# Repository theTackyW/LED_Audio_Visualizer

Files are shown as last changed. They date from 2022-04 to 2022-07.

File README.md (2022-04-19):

# LED_Audio_Visualizer
### Light DJ project

- This personal project utilizes MSGEQ7 to divide incoming audio signal into seven frequency bands and represents them as spectrum on 7 corresponding NeoPixel Sticks
Audio signal can be recieved by either a 3.5mm headphone jack or a microphone.

## Arduino Program and Functions
### LED_Audio_Visualizer.ino

> **void loop()**
> 
> - main function that read outputs of MSGEQ7, volume sensitivity nobe(volSen), and brightness nobe(brightControl); Update NeoPixel Sticks status.

> **void SingleLED(int v, int band)**
> 
> - Reads the output from MSGEQ7 for one specific band. Compare value with threadholds to determine how many LEDs need to be light up for each band

> **void setLEDnum(int n, int band, double bright)**
> 
> - function that uses .setPixelColor() function in the included <Adafruit_NeoPixel.h>. Considers brightness and color.
> calls the colorFade functions for color fade from [r1,g1,b1] to [r2,g2,b2] based on band level

> **void clearAll(int band)**
> 
> - set all LEDs on one band to OFF

> **double colorFadeR(int r1, int r2, int n)**

> **double colorFadeG(int g1, int g2, int n)**

> **double colorFadeB(int b1, int b2, int n)**

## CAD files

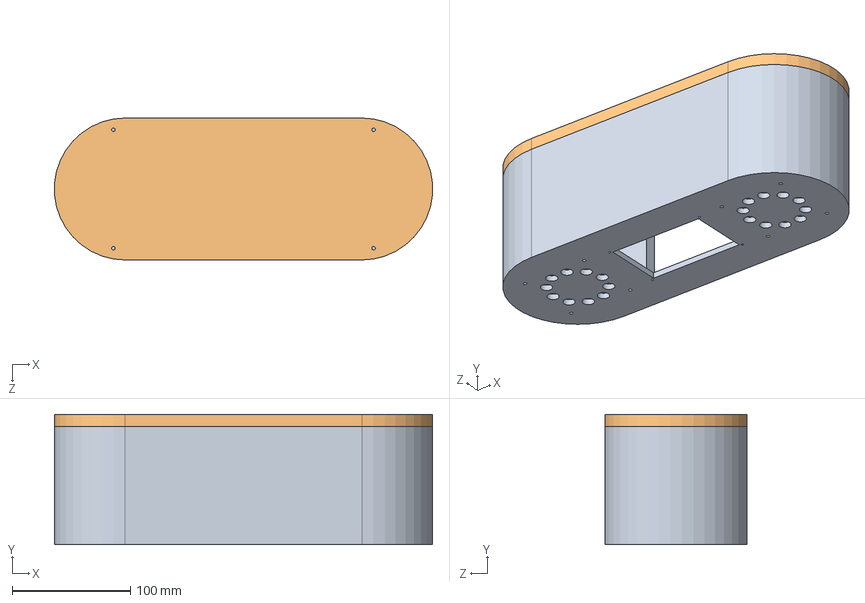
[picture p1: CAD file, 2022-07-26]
CAD/Speaker-case.SLDASM
319.6 x 110.0 x 120.0 mm
Front-case
back

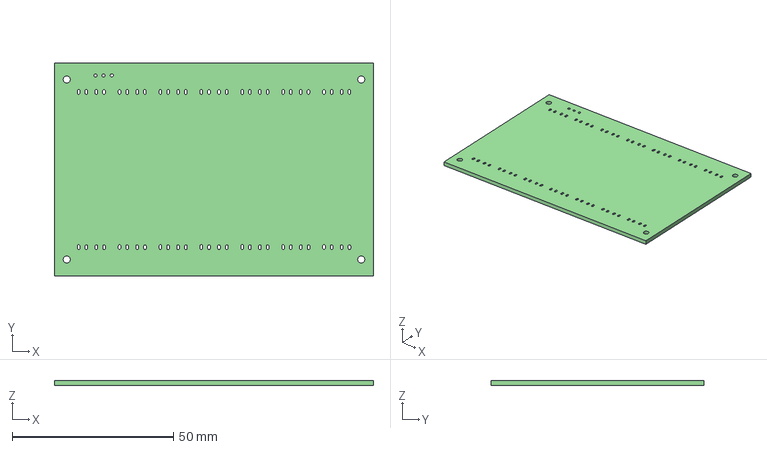
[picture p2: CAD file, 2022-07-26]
Adafruit_NeoPixel_bar/Adafruit_NeoPixel_bar.step
99.1 x 66.0 x 1.60 mm

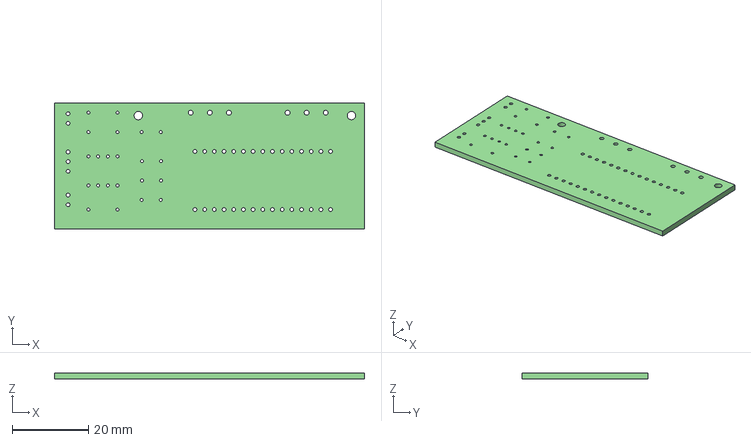
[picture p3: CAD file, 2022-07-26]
AV_Speaker/AV_Speaker.step
81.3 x 33.0 x 1.60 mm

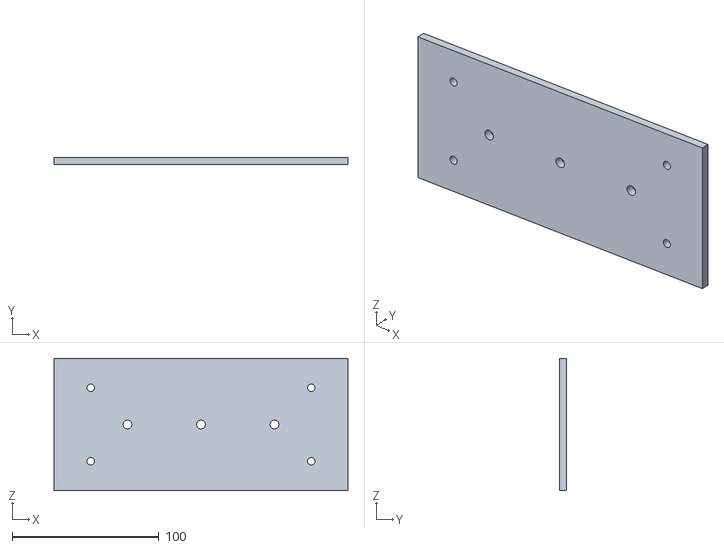
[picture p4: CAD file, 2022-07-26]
CAD/Top-cover.STL
200.0 x 5.00 x 90.0

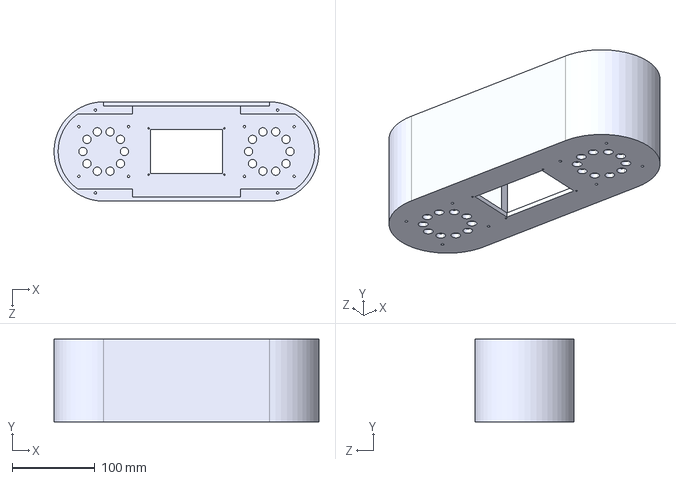
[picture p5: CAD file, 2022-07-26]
CAD/Front-case.STEP
320.0 x 100.0 x 120.0 mm

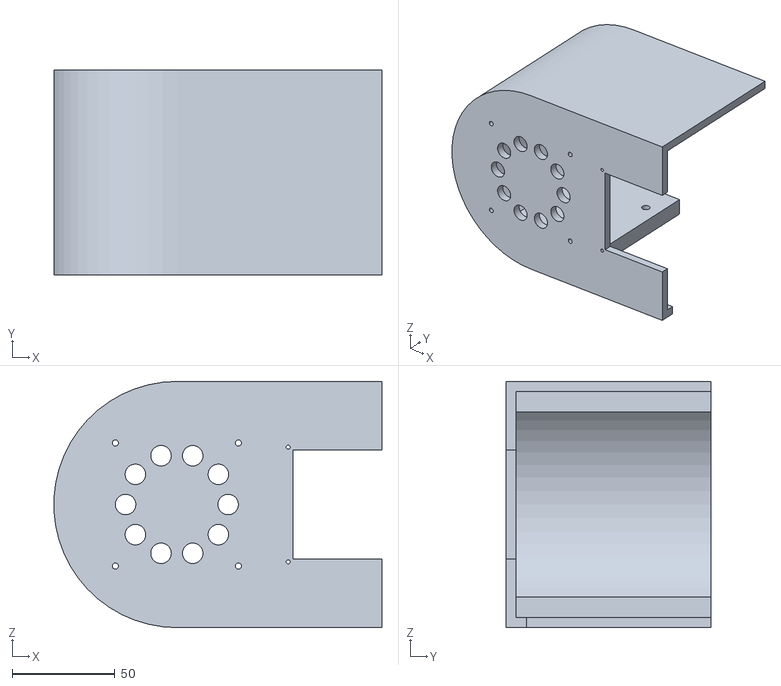
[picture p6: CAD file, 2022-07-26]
CAD/Front-case-right.STL
159.9 x 100.0 x 120.0

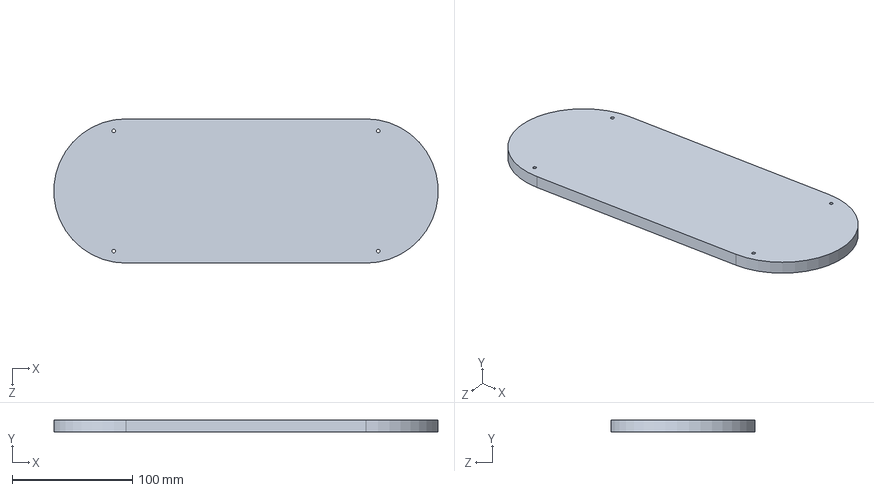
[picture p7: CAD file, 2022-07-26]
CAD/back.SLDPRT
319.6 x 10.0 x 120.0 mm

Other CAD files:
CAD/Front-case - left.STL
CAD/Front-case.SLDPRT
CAD/Front-case.STL

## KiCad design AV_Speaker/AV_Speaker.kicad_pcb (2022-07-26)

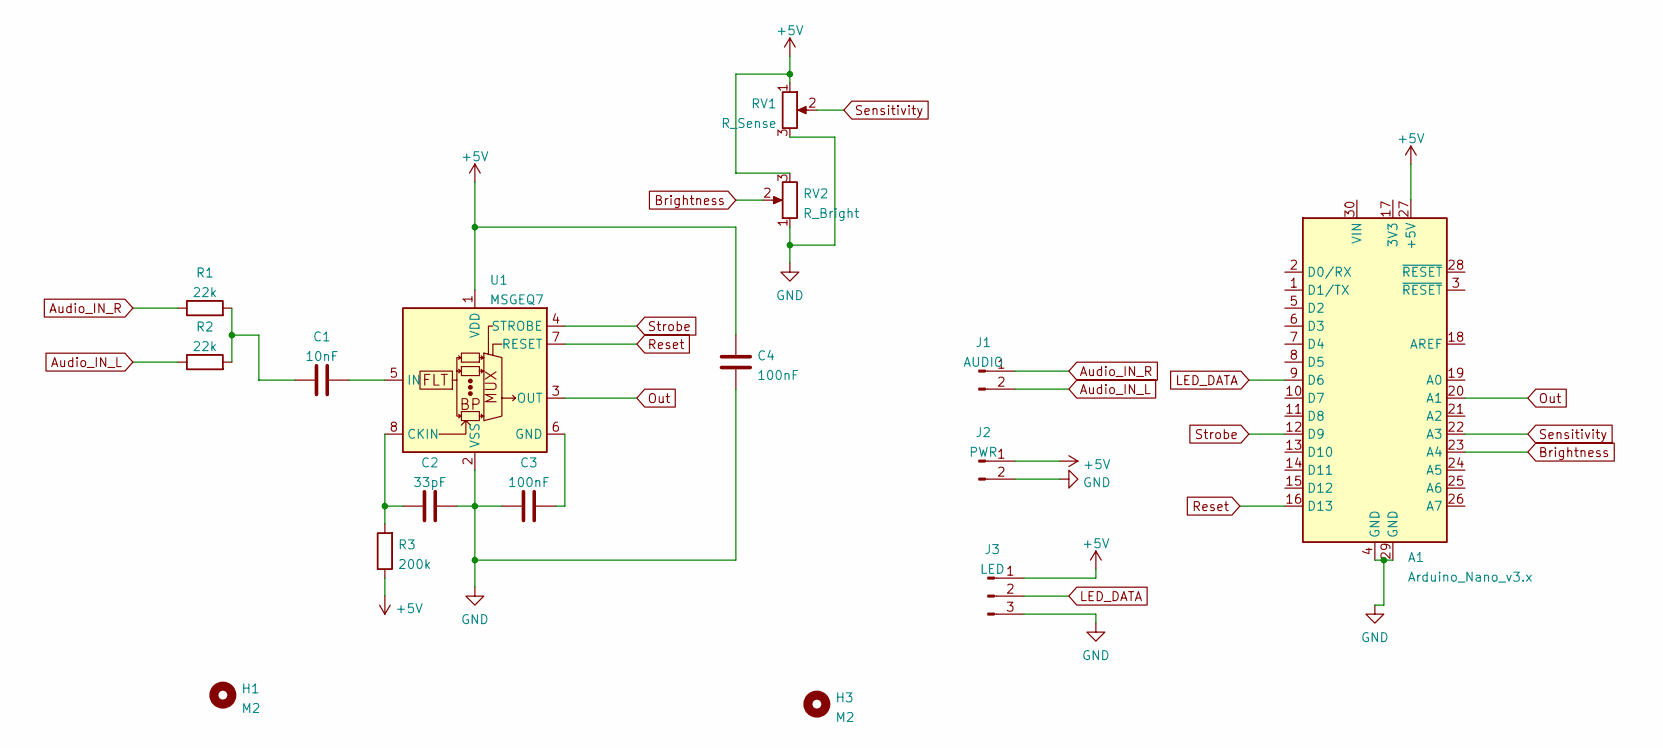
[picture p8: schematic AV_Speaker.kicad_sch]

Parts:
A1: Arduino_Nano_v3.x; Arduino_Nano
C1: 10nF; C_Disc_D4.3mm_W1.9mm_P5.00mm
C2: 33pF; C_Disc_D4.3mm_W1.9mm_P5.00mm
C3, C4: 100nF; C_Disc_D4.3mm_W1.9mm_P5.00mm
H1, H3: M2; MountingHole_2.2mm_M2
J1: AUDIO; PinHeader_1x02_P2.54mm_Vertical
J2: PWR; PinHeader_1x02_P2.54mm_Vertical
J3: LED; PinHeader_1x03_P2.54mm_Vertical
R1, R2: 22k; R_Axial_DIN0207_L6.3mm_D2.5mm_P7.62mm_Horizontal
R3: 200k; R_Axial_DIN0207_L6.3mm_D2.5mm_P7.62mm_Horizontal
RV1: R_Sense; Potentiometer_Piher_PC-16_Single_Horizontal
RV2: R_Bright; Potentiometer_Piher_PC-16_Single_Horizontal
U1: MSGEQ7; DIP-8_W7.62mm_LongPads

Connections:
+5V: A1.27 (+5V), C4.2, J2.1, J3.1, R3.1, RV1.1, RV2.3, U1.1 (VDD)
Audio_IN_L: J1.2, R2.1
Audio_IN_R: J1.1, R1.1
Brightness: A1.23 (A4), RV2.2
GND: A1.4 (GND), A1.29 (GND), C2.2, C3.1, C4.1, J2.2, J3.3, RV1.3, RV2.1, U1.2 (VSS)
LED_DATA: A1.9 (D6), J3.2
unnamed: C1.1, R1.2, R2.2
unnamed: C1.2, U1.5 (IN)
unnamed: C2.1, R3.2, U1.8 (CKIN)
unnamed: C3.2, U1.6 (GND)
Out: A1.20 (A1), U1.3 (OUT)
Reset: A1.16 (D13), U1.7 (RESET)
Sensitivity: A1.22 (A3), RV1.2
Strobe: A1.12 (D9), U1.4 (STROBE)

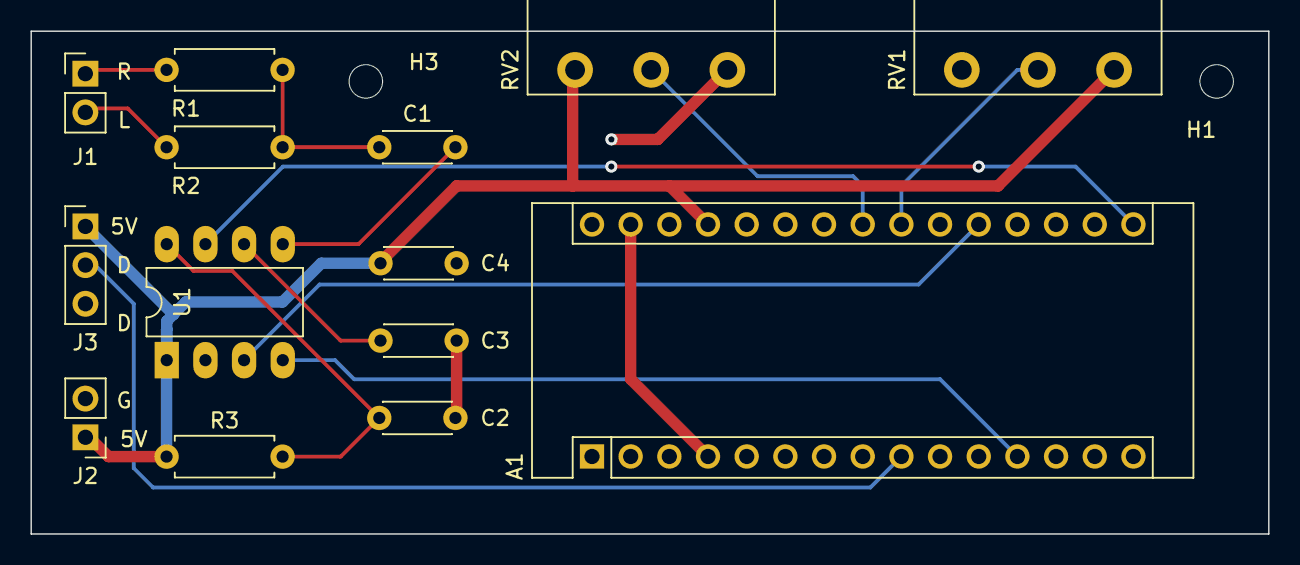
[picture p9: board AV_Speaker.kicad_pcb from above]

Board: 2 copper layers, 81.3 x 33.0 mm, 16 parts (0 on the bottom side), 14 nets.

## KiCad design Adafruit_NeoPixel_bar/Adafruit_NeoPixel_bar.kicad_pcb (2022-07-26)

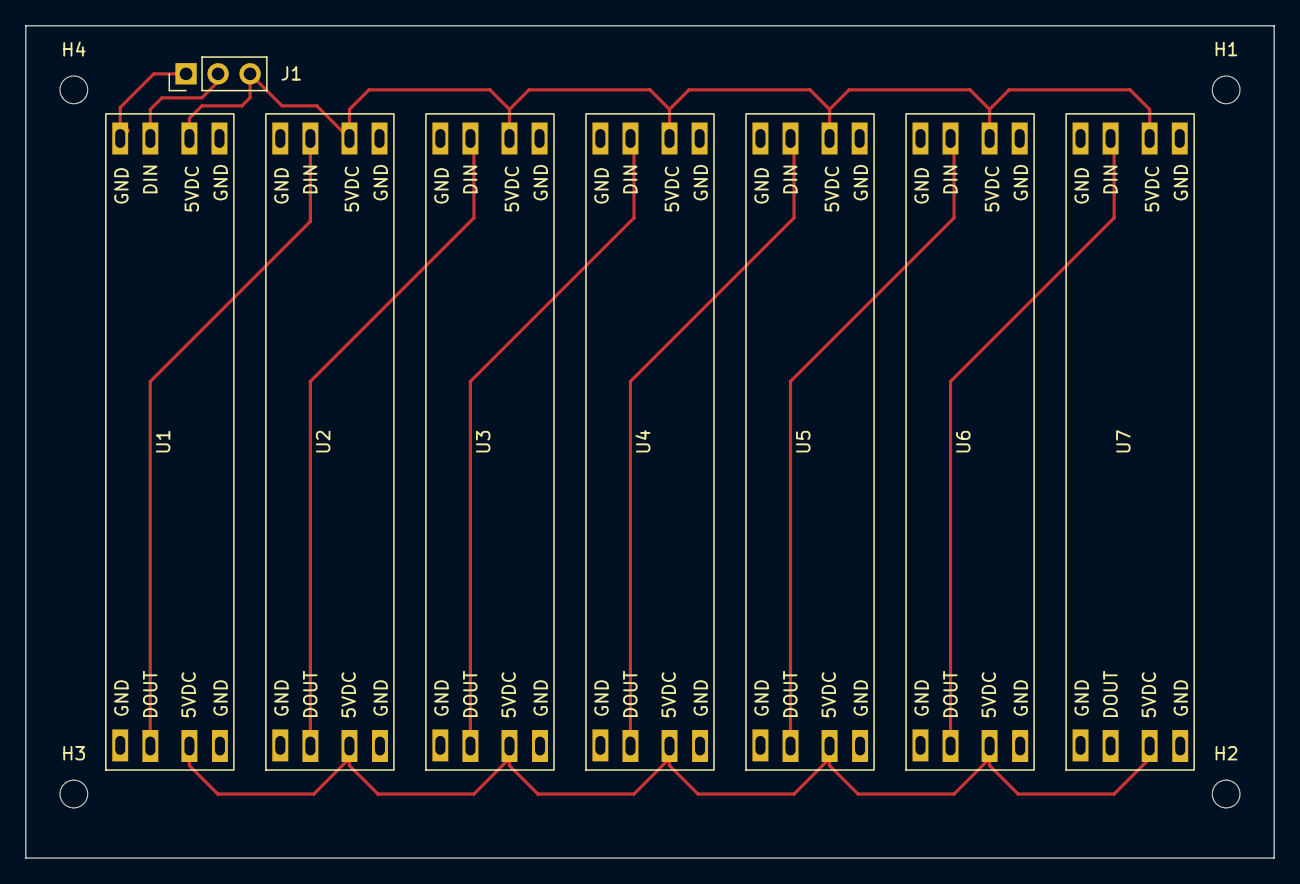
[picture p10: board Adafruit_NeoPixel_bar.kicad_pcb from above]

Board: 2 copper layers, 99.1 x 66.0 mm, 12 parts (0 on the bottom side), 9 nets.

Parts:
H1, H2, H3, H4: M2; MountingHole_2.2mm_M2
J1: 1x3; PinHeader_1x03_P2.54mm_Vertical
U1, U2, U3, U4, U5, U6, U7: NeoPixel_bar

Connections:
+5V: J1.3, U1.5VDC, U2.5VDC, U3.5VDC, U4.5VDC, U5.5VDC, U6.5VDC, U7.5VDC
GND: J1.1, U1.GND, U2.GND, U3.GND, U4.GND, U5.GND, U6.GND, U7.GND
unnamed: J1.2, U1.DIN
unnamed: U1.DOUT, U2.DIN
unnamed: U2.DOUT, U3.DIN
unnamed: U3.DOUT, U4.DIN
unnamed: U4.DOUT, U5.DIN
unnamed: U5.DOUT, U6.DIN
unnamed: U6.DOUT, U7.DIN

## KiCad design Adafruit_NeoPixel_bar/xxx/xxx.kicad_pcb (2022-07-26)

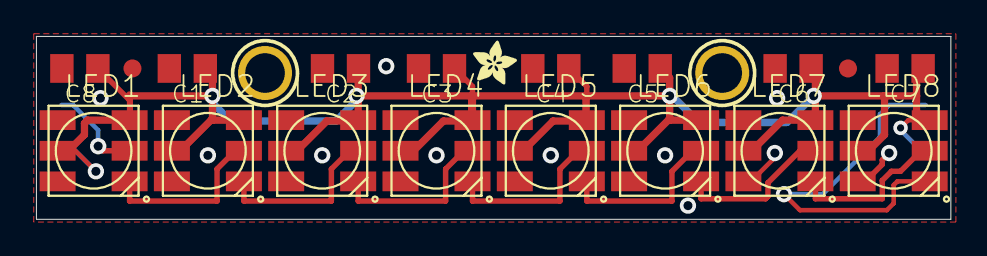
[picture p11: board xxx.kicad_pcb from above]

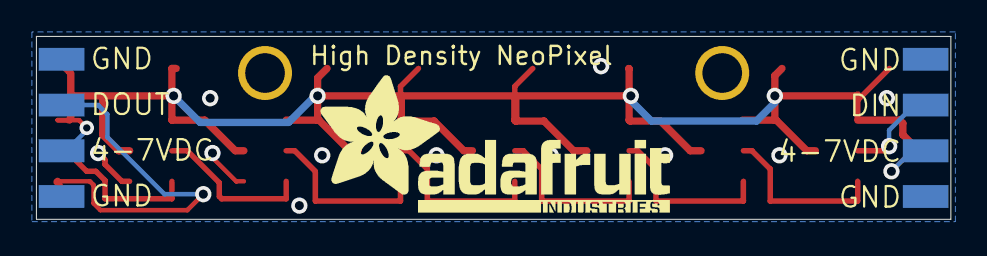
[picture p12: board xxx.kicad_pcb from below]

Board: 2 copper layers, 50.8 x 10.2 mm, 24 parts (3 on the bottom side), 11 nets.

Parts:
C1, C2, C3, C4, C5, C6, C7, C8: C0805K
CN1, CN2: 1X4SMT; 1X4-SMT
FID1, FID3: FIDUCIAL""; FIDUCIAL_1MM
LED1, LED2, LED3, LED4, LED5, LED6, LED7, LED8: WS28115050
U$1: ADAFRUIT_TEXT_20MM
U$2, U$3: MOUNTINGHOLE2.0; MOUNTINGHOLE_2.0_PLATED
U$4: ADAFRUIT_2.5MM

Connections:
+5V: C1.1, C2.1, C3.1, C4.1, C5.1, C6.1, C7.1, C8.1, CN1.3, CN2.2, LED1.LEDVDD, LED1.VDD, LED2.LEDVDD, LED2.VDD, LED3.LEDVDD, LED3.VDD, LED4.LEDVDD, LED4.VDD, LED5.LEDVDD, LED5.VDD, LED6.LEDVDD, LED6.VDD, LED7.LEDVDD, LED7.VDD, LED8.LEDVDD, LED8.VDD
GND: C1.2, C2.2, C3.2, C4.2, C5.2, C6.2, C7.2, C8.2, CN1.1, CN1.4, CN2.1, CN2.4, LED1.VSS, LED2.VSS, LED3.VSS, LED4.VSS, LED5.VSS, LED6.VSS, LED7.VSS, LED8.VSS
unnamed: LED1.DO, LED2.DI
unnamed: LED2.DO, LED3.DI
unnamed: LED3.DO, LED4.DI
unnamed: LED4.DO, LED5.DI
unnamed: LED5.DO, LED6.DI
unnamed: LED6.DO, LED7.DI
unnamed: LED7.DO, LED8.DI
unnamed: CN2.3, LED1.DI
unnamed: CN1.2, LED8.DO

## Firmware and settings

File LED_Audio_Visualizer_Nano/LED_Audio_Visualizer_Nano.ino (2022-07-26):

#include <Adafruit_NeoPixel.h>
#define NUMPIXELS 56
#define PIN 6
#define STROBE 9
#define RESET 13
#define OUTPIN A1
#define AUDIO A0
#define Vknob A3
#define Bknob A4
Adafruit_NeoPixel pixels(NUMPIXELS, PIN, NEO_GRB + NEO_KHZ800);
int level[7]; 

//SET GLOBAL VARIABLES
double volSen; //volume sensitivity
double brightControl; //global brightness
  
void setup() {
  #if defined(__AVR_ATtiny85__) && (F_CPU == 16000000)
    clock_prescale_set(clock_div_1);
  #endif
  pixels.begin();
  Serial.begin(9600);
  pixels.clear();

  //pinMode(MIC, INPUT);
  //pinMode(4, INPUT);
    // Define our pin modes
  pinMode(STROBE, OUTPUT);
  pinMode(RESET,  OUTPUT);
  pinMode(OUTPIN,    INPUT);
 
  // Create an initial state for our pins
  digitalWrite (RESET,  LOW);
  digitalWrite (STROBE, LOW);
  delay        (1);
 
  // Reset the MSGEQ7 as per the datasheet timing diagram
  digitalWrite (RESET,  HIGH);
  delay        (1);
  digitalWrite (RESET,  LOW);
  digitalWrite (STROBE, HIGH); 
  delay        (5);


}

void loop() {
 int s = 0;
 //volSen = analogRead(Vknob)/1024.0;
 volSen = 0.9;
 //brightControl = analogRead(Bknob)/1024.0;
 brightControl = 0.1;
 Serial.print(volSen);
 Serial.print("   ");
 Serial.print(brightControl);
 Serial.println();
 for (int i = 0; i < 7; i++) {
    digitalWrite       (STROBE, LOW);
    delayMicroseconds  (5);                  // Delay necessary due to timing diagram
    int x = analogRead(OUTPIN);
    level[i] = x;
    digitalWrite       (STROBE, HIGH);
    delayMicroseconds  (5);                    // Delay necessary due to timing diagram
    s = s+x; 
  }
 Serial.println("  ");
  SingleLED(level[0],0);
  SingleLED(level[1],1);
  SingleLED(level[2],2);
  SingleLED(level[3],3);
  SingleLED(level[4],4);
  SingleLED(level[5],5);
  SingleLED(level[6],6);

  //moved pixels.show() here to reduce blinking issue
  pixels.show();   // Send the updated pixel colors to the hardware.
}


void SingleLED(int v,int band){
 //v = v-90;
 //Serial.println(v);
  int t0 = 149*volSen;
  int t1 = 150*volSen;
  int t2 = 250*volSen;
  int t3 = 400*volSen;
  int t4 = 500*volSen;
  int t5 = 600*volSen;
  int t6 = 700*volSen;
  int t7 = 800*volSen;
  int t8 = 980*volSen;
  if (v <= t0){
    clearAll(band);
    }
  if (v > t1){
    setLEDnum(1,band,v-t1);
  }
  if (v >= t2){
    setLEDnum(2,band,v-t2);
  }
  if (v >= t3){
    setLEDnum(3,band,v-t3);
  }
  if (v >= t4){
    setLEDnum(4,band,v-t4);
  }
  if (v >= t5){
    setLEDnum(5,band,v-t5);
  }
  if (v >= t6){
    setLEDnum(6,band,v-t6);
  }
  if (v >= t7){
    setLEDnum(7,band,v-t7);
  }
  if (v >= t8){
    setLEDnum(8,band,v-t8);
  }
}


void setLEDnum(int n,int band,double bright){
 double maxBright = (255/255)*brightControl;
 bright = (bright/255)*brightControl;
 double r = colorFadeR(143,0,n);
 double g = colorFadeG(39,155,n);
 double b = colorFadeB(233,0,n);
// if (band%2==0){
//   for(int i=band*8; i<band*8+8; i++) { // For each pixel...
//        if(i<n+band*8-1){
//          pixels.setPixelColor(i, pixels.Color(r*maxBright, g*maxBright, b*maxBright));
//        }
//        else if(i == n+band*8-1){
//          pixels.setPixelColor(i, pixels.Color(r*bright, g*bright, b*bright));
//        }
//        else{
//          pixels.setPixelColor(i, pixels.Color(0,0,0));
//        }
//   }
// }
// else{
   for(int i=(band+1)*8-1; i>(band+1)*8-1-8; i--) { // For each pixel...
        if (i > (band+1)*8-1-n+1){
          pixels.setPixelColor(i, pixels.Color(r*maxBright, g*maxBright, b*maxBright));
        }
        else if (i == (band+1)*8-1-n+1){
          pixels.setPixelColor(i, pixels.Color(r*bright, g*bright, b*bright));
        }
        else{
          pixels.setPixelColor(i, pixels.Color(0,0,0));
        }
   //}
 }
}


void clearAll(int band){
  for(int i=band*8; i<band*8+8; i++) { // For each pixel...
      pixels.setPixelColor(i, pixels.Color(0, 0, 0));
      }
      pixels.show();
  }

//fade color from [r1,g1,b1] to [r2,g2,b2] (low to high)
double colorFadeR(int r1,int r2,int n){
  double r = r1+n*(r2-r1)/8;
  return r;
}
double colorFadeG(int g1,int g2,int n){
  double g = g1+n*(g2-g1)/8;
  return g;
}
double colorFadeB(int b1,int b2,int n){
  double b = b1+n*(b2-b1)/8;
  return b;
}

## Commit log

2022-01-11 Fix formatting
    Deleted some unused code and comments
    [LED_Audio_Visualizer.ino]
2022-04-19 Update LED_Audio_Visualizer.ino
    Changed fading colors
2022-07-26 Big Update
    Updated CAD case design; code for Nano; code for actual orientation of the LED matrix
    [AV_Speaker-B_Cu.gbr, AV_Speaker-B_Mask.gbr, AV_Speaker-B_Paste.gbr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]
